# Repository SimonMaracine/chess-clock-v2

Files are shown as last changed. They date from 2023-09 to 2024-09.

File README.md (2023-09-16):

# Chess Clock V2

Two years ago I made from scratch, together with a friend, a chess clock. We
used an Arduino Uno and some bought parts, like buttons, wires, an LCD screen
and other things like that, but everything else was made by us, including the
case and the internal wiring with a handmade PCB.

This time we would like to improve everything: the software, the case, the
wiring, the buttons and everything else.

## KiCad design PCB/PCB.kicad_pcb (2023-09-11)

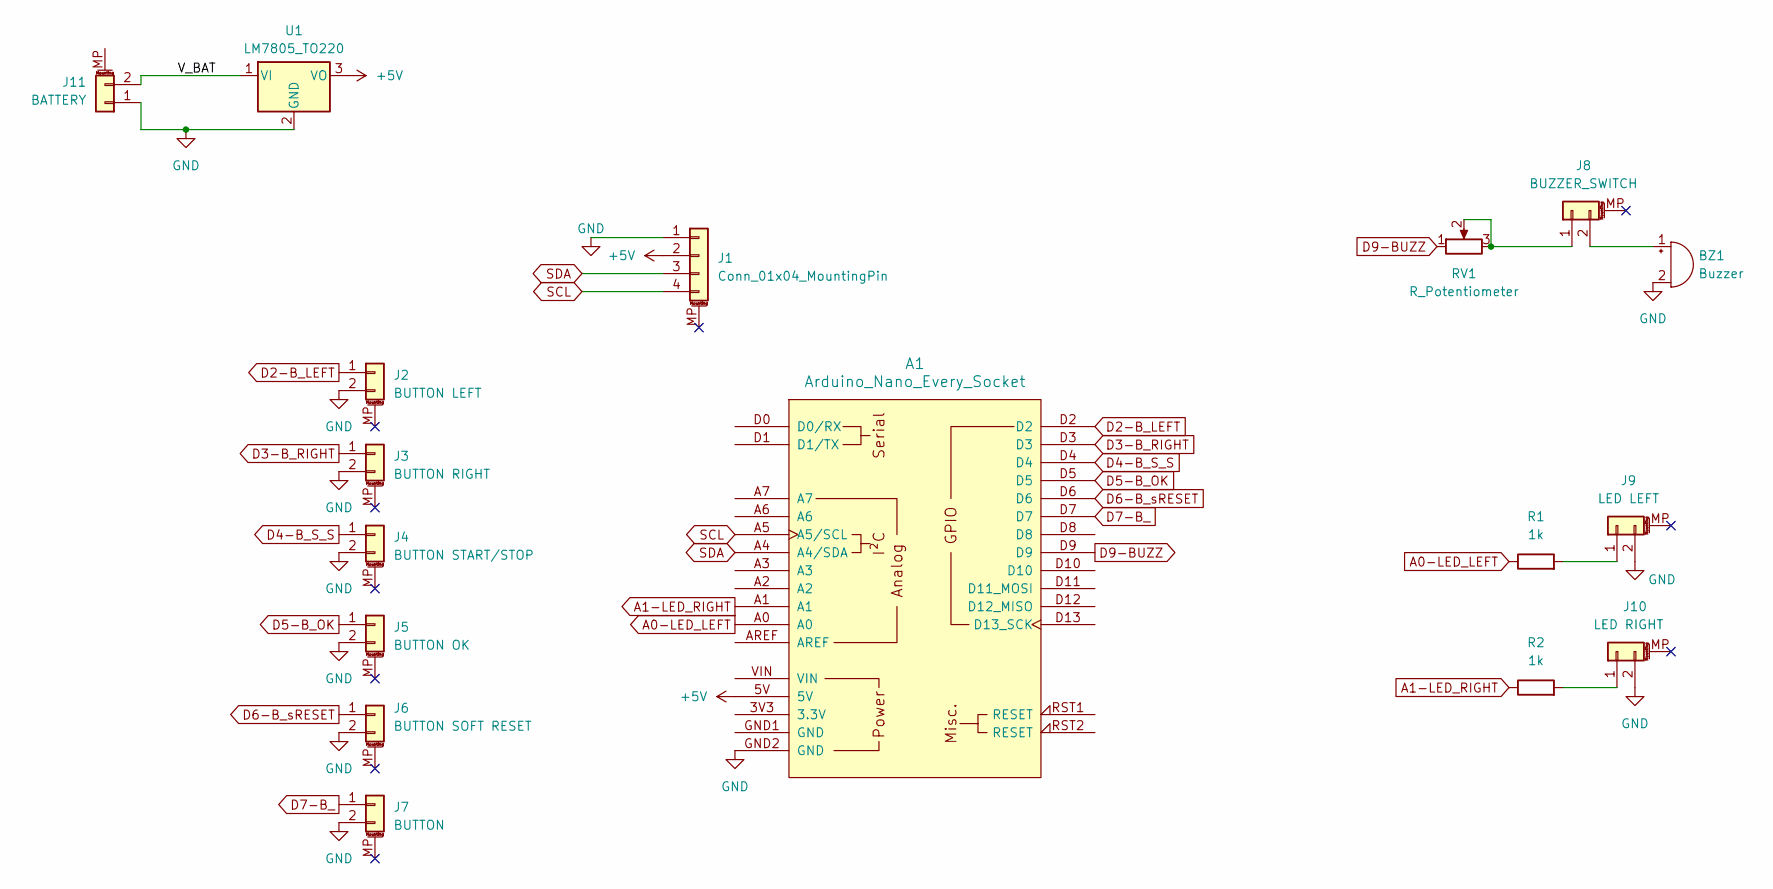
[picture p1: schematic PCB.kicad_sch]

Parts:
A1: Arduino_Nano_Every_Socket
BZ1: Buzzer; Buzzer_12x9.5RM7.6
J1: Conn_01x04_MountingPin; PinHeader_1x04_P2.54mm_Vertical
J2: BUTTON LEFT; PinHeader_1x02_P2.54mm_Vertical
J3: BUTTON RIGHT; PinHeader_1x02_P2.54mm_Vertical
J4: BUTTON START/STOP; PinHeader_1x02_P2.54mm_Vertical
J5: BUTTON OK; PinHeader_1x02_P2.54mm_Vertical
J6: BUTTON SOFT RESET; PinHeader_1x02_P2.54mm_Vertical
J7: BUTTON; PinHeader_1x02_P2.54mm_Vertical
J8: BUZZER_SWITCH; PinHeader_1x02_P2.54mm_Vertical
J9: LED LEFT; PinHeader_1x02_P2.54mm_Vertical
J10: LED RIGHT; PinHeader_1x02_P2.54mm_Vertical
J11: BATTERY; PinHeader_1x02_P2.54mm_Vertical
R1, R2: 1k; R_Axial_DIN0207_L6.3mm_D2.5mm_P10.16mm_Horizontal
RV1: R_Potentiometer; Potentiometer_ACP_CA9-V10_Vertical
U1: LM7805_TO220; TO-220-3_Vertical

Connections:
+5V: A1.5V, J1.2, U1.3 (VO)
/V_BAT: J11.2, U1.1 (VI)
A0-LED_LEFT: A1.A0, R1.1
A1-LED_RIGHT: A1.A1, R2.1
D2-B_LEFT: A1.D2, J2.1
D3-B_RIGHT: A1.D3, J3.1
D4-B_S_S: A1.D4, J4.1
D5-B_OK: A1.D5, J5.1
D6-B_sRESET: A1.D6, J6.1
D7-B_: A1.D7, J7.1
D9-BUZZ: A1.D9, RV1.1
GND: A1.GND1 (GND), A1.GND2 (GND), BZ1.2 (+), J1.1, J2.2, J3.2, J4.2, J5.2, J6.2, J7.2, J9.2, J10.2, J11.1, U1.2 (GND)
unnamed: BZ1.1 (-), J8.2
unnamed: J8.1, RV1.2, RV1.3
unnamed: J9.1, R1.2
unnamed: J10.1, R2.2
SCL: A1.A5 (A5/SCL), J1.4
SDA: A1.A4 (A4/SDA), J1.3

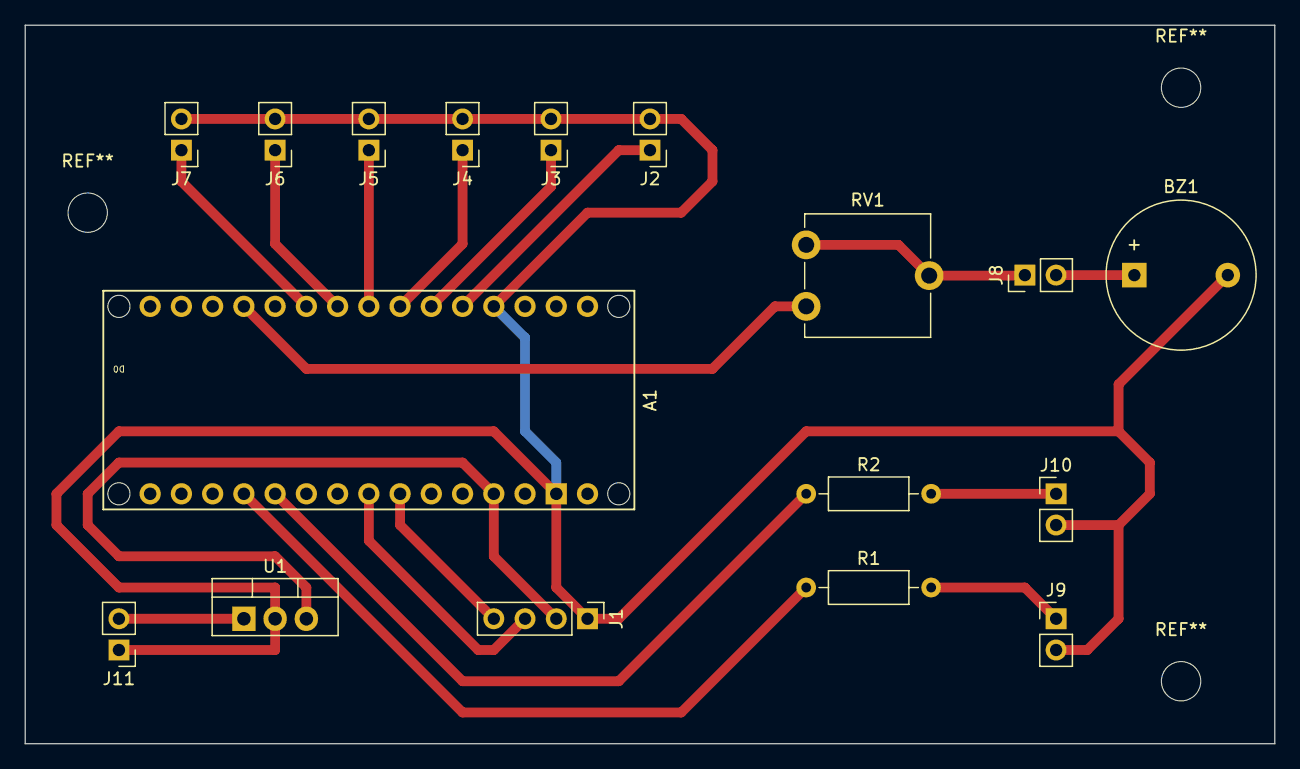
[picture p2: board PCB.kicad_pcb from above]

Board: 4 copper layers, 101.6 x 58.4 mm, 17 parts (0 on the bottom side), 18 nets.

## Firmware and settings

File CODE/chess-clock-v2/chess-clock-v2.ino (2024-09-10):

#include "context.hpp"
#include "definitions.hpp"
#include "states.hpp"
#include "characters.hpp"
#include "data.hpp"

static void setup_lcd(LiquidCrystal& lcd)
{
    lcd.begin(16, 2);
    lcd.createChar(CharacterEmptyRectangle, CHARACTERS[CharacterEmptyRectangle]);
    lcd.createChar(CharacterFilledRectangle, CHARACTERS[CharacterFilledRectangle]);
    lcd.createChar(CharacterLeftPipe, CHARACTERS[CharacterLeftPipe]);
    lcd.createChar(CharacterRightPipe, CHARACTERS[CharacterRightPipe]);
    lcd.createChar(CharacterTurnIndicator, CHARACTERS[CharacterTurnIndicator]);
    lcd.createChar(CharacterStartFlag, CHARACTERS[CharacterStartFlag]);
    lcd.createChar(CharacterUpArrow, CHARACTERS[CharacterUpArrow]);
    lcd.createChar(CharacterDownArrow, CHARACTERS[CharacterDownArrow]);
}

static chess_clock::Context g_ctx;
static Data g_data;

void setup()
{
    Serial.begin(9600);

    // Allocate all states
    StartupState startup {g_ctx};
    MenuState menu {g_ctx};
    ModesState modes {g_ctx};
    TimeState time {g_ctx};
    PreTimeState pre_time {g_ctx};
    DecisecondsState deciseconds {g_ctx};
    TwoClockUpState two_clock_up {g_ctx};
    TwoClockDownState two_clock_down {g_ctx};
    OneClockUpState one_clock_up {g_ctx};  // FIXME progress bar not working
    OneClockDownState one_clock_down {g_ctx};
    DiceState dice {g_ctx};

    g_ctx.add_state(startup);
    g_ctx.add_state(menu);
    g_ctx.add_state(modes);
    g_ctx.add_state(time);
    g_ctx.add_state(pre_time);
    g_ctx.add_state(deciseconds);
    g_ctx.add_state(two_clock_up);
    g_ctx.add_state(two_clock_down);
    g_ctx.add_state(one_clock_up);
    g_ctx.add_state(one_clock_down);
    g_ctx.add_state(dice);

    g_ctx.add_button(BUTTON_LEFT_PLAYER);
    g_ctx.add_button(BUTTON_RIGHT_PLAYER);
    g_ctx.add_button(BUTTON_START_STOP);
    g_ctx.add_button(BUTTON_SOFT_RESET);
    g_ctx.add_button(BUTTON_OK);

    g_ctx.initialize(startup, setup_lcd, &g_data);

    pinMode(BUZZER, OUTPUT);
    pinMode(LED_LEFT, OUTPUT);
    pinMode(LED_RIGHT, OUTPUT);
}

void loop()
{
    g_ctx.update();
}

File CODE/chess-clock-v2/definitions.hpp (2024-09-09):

#pragma once

#define PIN_RS 2
#define PIN_E 3
#define PIN_D4 4
#define PIN_D5 5
#define PIN_D6 6
#define PIN_D7 7

#define BUZZER 9
#define LED_LEFT 11
#define LED_RIGHT 10

#define BUTTON_LEFT_PLAYER A0
#define BUTTON_RIGHT_PLAYER A1
#define BUTTON_START_STOP A2
#define BUTTON_SOFT_RESET A3
#define BUTTON_OK A4

enum Button
{
    ButtonLeftPlayer,
    ButtonRightPlayer,
    ButtonStartStop,
    ButtonSoftReset,
    ButtonOk
};

enum State
{
    StateStartup,
    StateMenu,
    StateModes,
    StateTime,
    StatePreTime,
    StateDeciseconds,
    StateTwoClockUp,
    StateTwoClockDown,
    StateOneClockUp,
    StateOneClockDown,
    StateDice
};

enum Menu
{
    MenuModes,
    MenuTime,
    MenuDeciseconds,
    MenuStart,

    Menu_Count
};

// Uses more memory :P
static constexpr int MENU_CURSOR[4] {
    2, 6, 10, 14
};

enum Mode
{
    ModeTwoClockUp,
    ModeTwoClockDown,
    ModeOneClockUp,
    ModeOneClockDown,
    ModeDiceOne,
    ModeDiceTwo,

    Mode_Count
};

enum class TimeMode
{
    Minutes,
    Seconds
};

enum class Player
{
    Left,
    Right
};

// Defined in deciseconds
#define NINETY_MINUTES_D 54000
#define THIRTY_MINUTES_D 18000
#define THREE_MINUTES_D 1800
#define ONE_MINUTE_D 600
#define ONE_SECOND_D 10

// Defined in milliseconds
#define ONE_SECOND_M 1000
#define ONE_DECISECOND_M 100
#define TWO_DECISECONDS_M 200
